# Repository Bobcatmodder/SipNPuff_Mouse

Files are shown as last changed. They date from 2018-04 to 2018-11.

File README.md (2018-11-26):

# The 'Sup - a Mouse for Quadriplegics (SipNPuff_Mouse)

This is a mouse for Quadriplegics and other mobility impaired people, intended to be used with one's mouth. 
This is the repository for code, STL files, and any guides for the mouse, which I show how to build at https://www.instructables.com/id/The-Sup-a-Mouse-for-Quadriplegics-Low-Cost-and-Ope/.

This is a mouse input device intended to be used by Quadriplegics and other mobility impaired people. 
It's a combination of a joystick and a sip-n-puff controller, and is controller by one's mouth. 

Hardware:
Arduino Pro Micro, normal joystick module, and an MPXV7002DP (-0.3 to 0.3 PSI) pressure sensor, enclosed in a 3D printed case.

Software:
A single sketch running on the Arduino, samples values from the joystick and pressure sensor and inputs mouse commands based off that.

If you happen to be wanting one of these but do not wish to build it yourself, please contact me through Instructables. I will be more than happy to make you one at a reasonable price.

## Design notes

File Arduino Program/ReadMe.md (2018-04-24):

The arduino program.

Requires no special libraries or boards, should just be plug and play.

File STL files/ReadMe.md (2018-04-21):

All the STL files.

Mouthpiece03 should be scaled to 1.03 size on the X and Y axis, and left as is for Z (This is to account for shrinkage while annealing). Also print at 100% infill (To keep water from seeping in when it's being washed).

AdapterII is to be printed in a flexible filament.

Lid will print best with supports set to "everywhere", but it may print fine without depending on your printer.

Everything else is fine, just make sure the orientation is OK. If the part shows up too small, simply scale it to 10x size. (They show up too small in Cura)

Other print settings: Speed is default, infill is 45, layer height is best at 0.1MM, but for the frame, lid, and GoProMount files it can be 0.2MM.

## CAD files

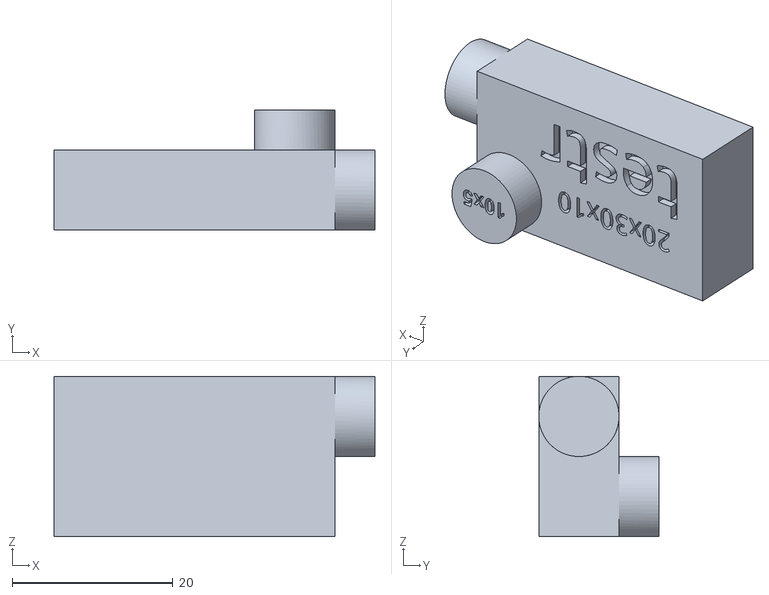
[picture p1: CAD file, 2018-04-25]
STL files/AnnealingTester.stl
40.0 x 15.0 x 20.0

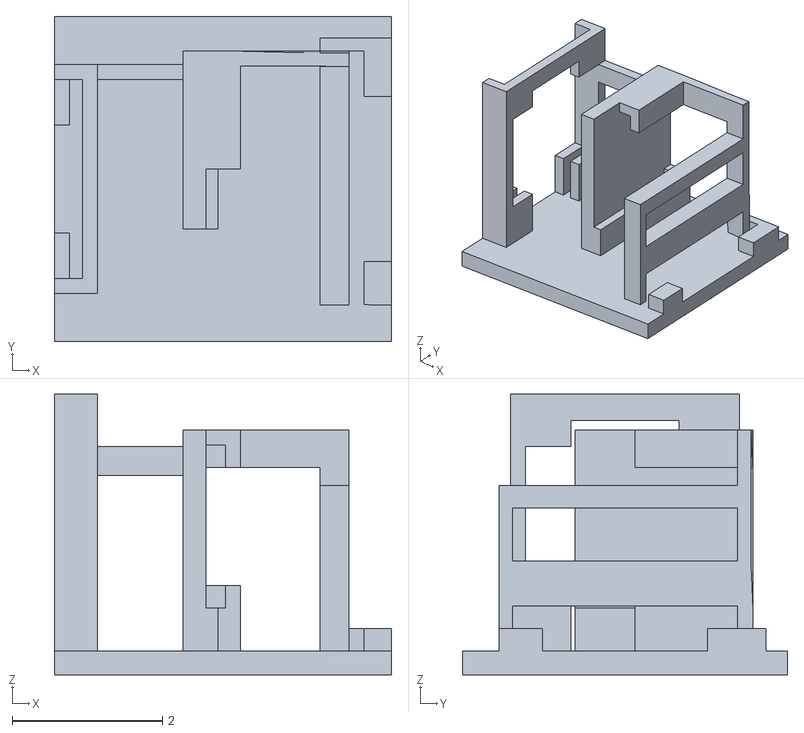
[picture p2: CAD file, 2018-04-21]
STL files/Frame.stl
4.49 x 4.33 x 3.74

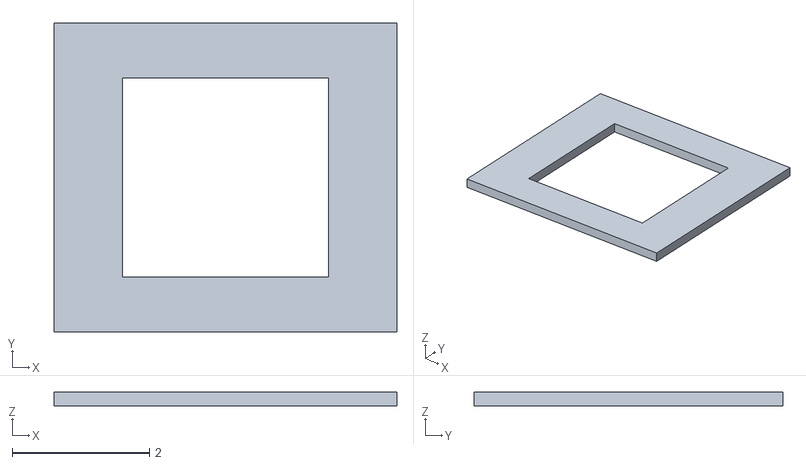
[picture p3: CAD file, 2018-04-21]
STL files/FacePlate.stl
5.00 x 4.50 x 0.2

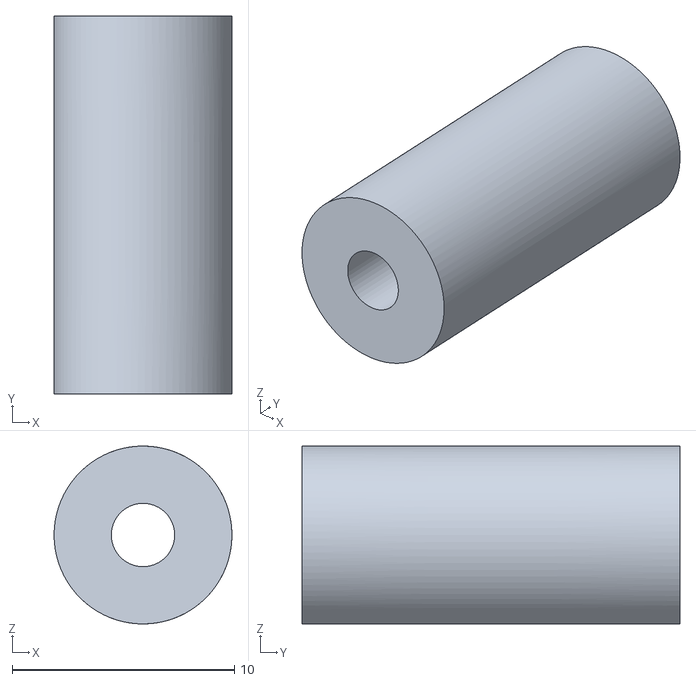
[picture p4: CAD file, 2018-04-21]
STL files/TubingAdapter.stl
8.00 x 17.0 x 8.00

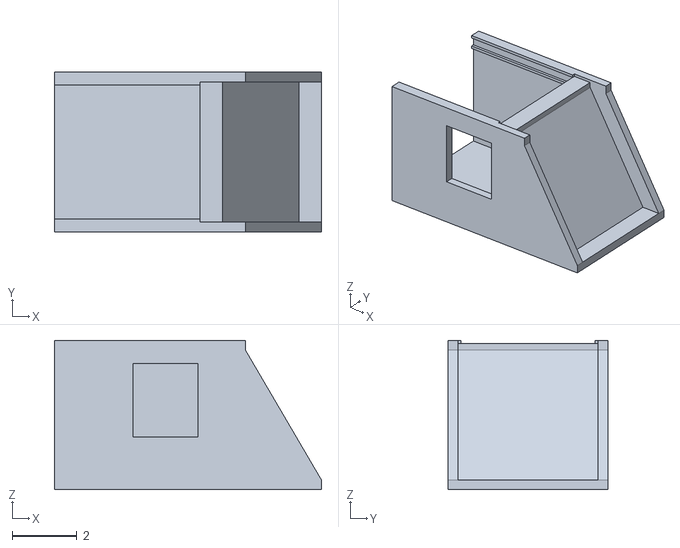
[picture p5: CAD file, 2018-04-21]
STL files/Case.stl
8.23 x 4.93 x 4.61

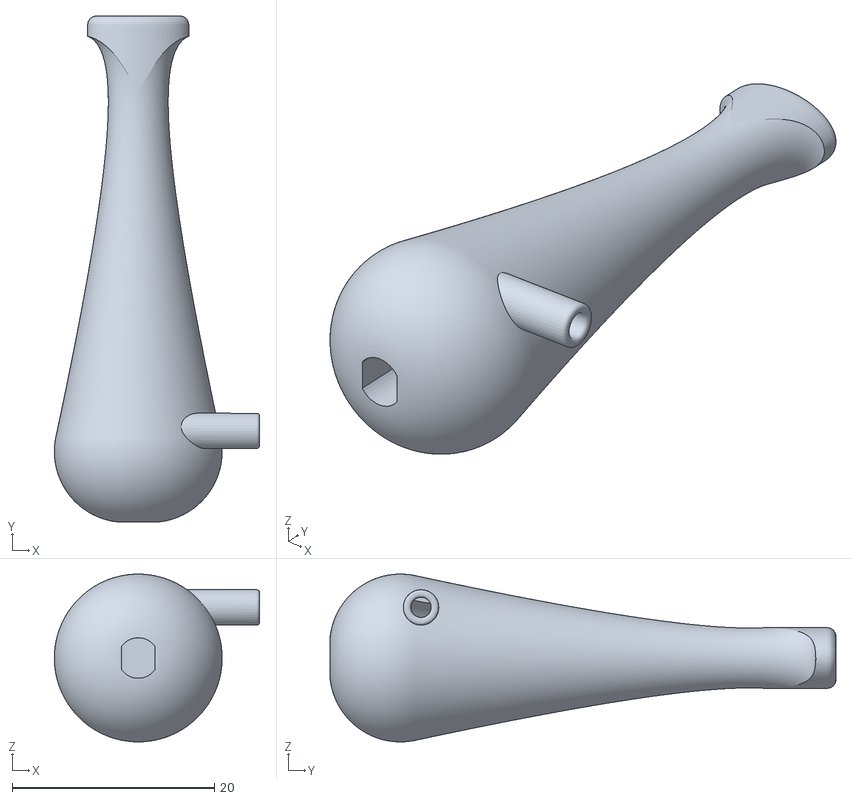
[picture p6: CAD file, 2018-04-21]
STL files/MouthPiece.stl
20.3 x 50.0 x 16.6

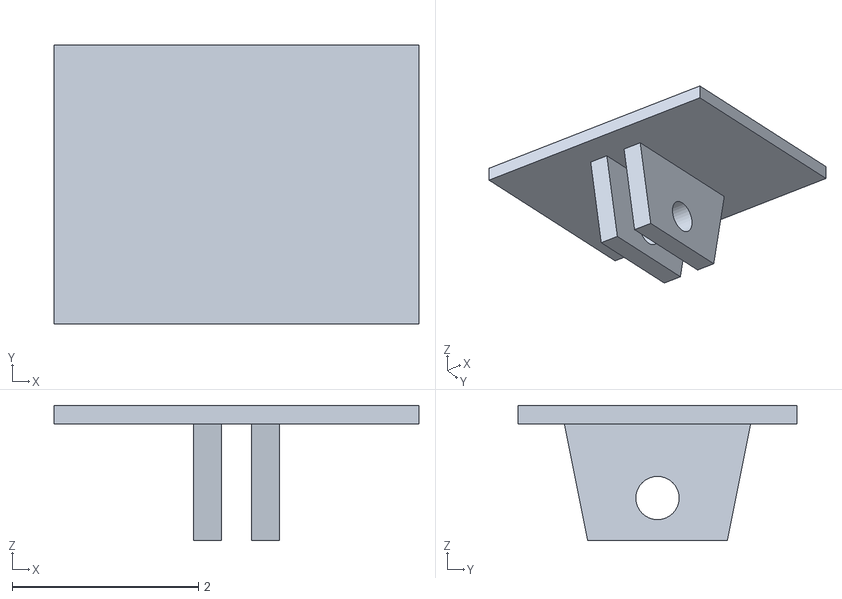
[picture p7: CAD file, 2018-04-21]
STL files/GoProClip.stl
3.92 x 3.00 x 1.45

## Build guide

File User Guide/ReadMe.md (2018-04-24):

User guide here: Currently it's pretty simplistic, for more info check out the Instructable.

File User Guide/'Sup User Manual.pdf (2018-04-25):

## ‘Sup Sip-n-Puff user manual

Mouse actions:
Action: | Input: | Uses:
Hard sip | Right click | Options for folders, files or web links
Soft sip | Scroll down | To move a webpage down
Soft puff | Scroll up | To move a webpage up
Hard puff | Left click | Open programs, files, links, or items.
2 short hard puffs | Double click | To open programs, files or folders
Holding a hard puff | Clicking & dragging | To move items, files, folders, or programs

Copyright © 2018, Jacob Field. This work is licensed under a Creative Commons Attribution 4.0 International License. (http://creativecommons.org/licenses/by/4.0/)

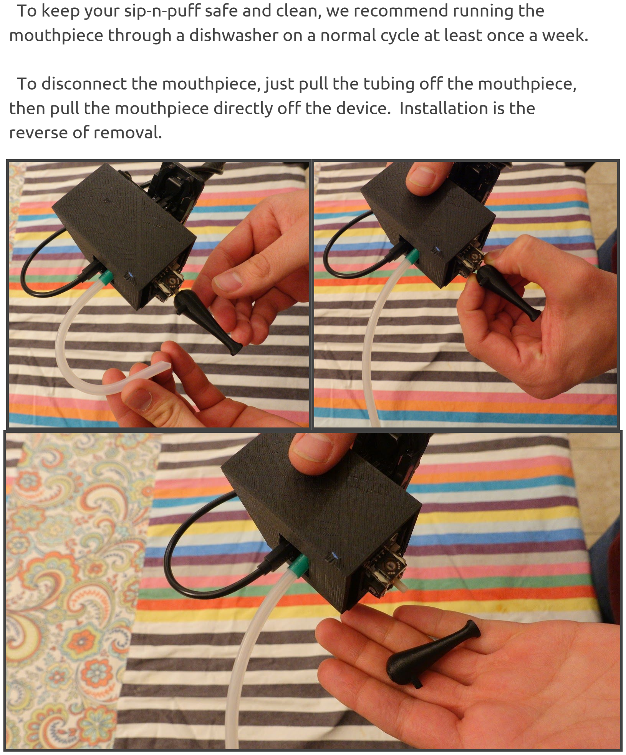
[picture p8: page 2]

To keep your sip-n-puff safe and clean, we recommend running the mouthpiece through a dishwasher on a normal cycle at least once a week.

To disconnect the mouthpiece, just pull the tubing off the mouthpiece, then pull the mouthpiece directly off the device. Installation is the reverse of removal.

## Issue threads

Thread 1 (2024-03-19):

Providing STEP files for SipNPuff

JsonX1ng, 2024-03-19:
Hello!
I'm a student from Simon Fraser University and we're making a SipNPuff fishing rod. I'm interested in integrating your module into our design. Since our team is using an Arduino UNO + prototyping shield instead of the pro micro in your design, we are planning to modify the case, frame and mouthpiece. Would it be possible for you to provide the STEP/F3z/SLDPRT files for the design?

Thanks!
-Jason

Bobcatmodder, 2024-03-20:
Hi Jason!

I might still have the files, but - if your team has any 3D modeling
design, I'm pretty sure you'll be able to make a much better design - I
made these with a friend back in 2017 when we didn't have any experience.
Let me know if you still want the files though!

Jacob

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

Closed 2024-03-27.

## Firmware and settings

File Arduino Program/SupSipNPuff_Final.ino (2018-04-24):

/*
MIT License

Copyright (c) 2018 Jacob Field

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
--The source code, design files, and links to documentation for this project can
--be found at https://github.com/Bobcatmodder/SipNPuff_Mouse/.
*/

#include <Mouse.h>

//Pressure sensor sampling values
volatile byte sampleCounter = 0;
byte sampleLength = 12; //desired sample number minus one because computers are zero indexed
volatile int samples[13];
unsigned long sampleRoutineTimer = 0;
byte samplePeriod = 8;

//Mouse button state trackers
bool isLeftPressed = false;
bool isRightPressed = false;

//Cursor velocity variables (to do with precision and speed)
int wavelength = 15; // Distance/Period (Speed of cursor in pixels/iteration)
int period = 35; // Time/period (MS per iteration)
unsigned long cursorFrequencyTimer = 0; // Variable to time when to update the mouse

//Joystick threshold and analog value storing arrays
int joyThresh[] = {5, 5}; //Deadzone threshholds for X and Y axis of joystick
int reading[] = {0, 0}; //Array for storing the values of the readings from the joystick axis


void setup() { //Setup code, runs once at startup

  Mouse.begin(); //Take control of the mouse

  //Initialize the timers (these are used so we don't have to use a delay() function inside the loop)
  sampleRoutineTimer = millis() + samplePeriod;
  cursorFrequencyTimer = millis() + period;

}



void loop() { //Main loop, runs over and over as fast as possible

  //Code to run the sampling routine roughly every samplePeriod MS
  if (millis() >= sampleRoutineTimer) { //Otherwise if it's equal or less
    samplePressure();//Go run the function to sample the analog value from the pressure sensor
    sampleRoutineTimer = millis() + samplePeriod;//Reset the timer to 25 MS ahead of current millis() value
  }

  //If the sample buffer length has reached the desired number of samples, then X
  if (sampleCounter >= sampleLength + 1) {
    inputMouse(averagePressureValue());
    sampleCounter = 0; // Reset the sample buffer counter to zero
  }

  //Code to run the joystick analog value reading/conversion and mouse updating code every period MS
  if (millis() >= cursorFrequencyTimer) { //Otherwise if it's equal or less
    readAxis(1, 2);
    Mouse.move(reading[0], -reading[1], 0);
    cursorFrequencyTimer = millis() + period;//Reset the timer to 25 MS ahead of current millis() value
  }

}



//----------------Custom Functions----------------

//Sampling function to run every time the timer calls it
void samplePressure() {
  samples[sampleCounter] = analogRead(A0);
  sampleCounter += 1;
}


//Function to return the average value of the sample array
int averagePressureValue(){
  unsigned int averageReading = 0;
    for (byte x = 0; x <= sampleLength; x++) {
      averageReading += samples[x];
    }
    averageReading = averageReading / sampleLength + 1;
    return averageReading;
}


//Function that takes the average sample array pressure value, then sends a mouse command based off that pressure value
void inputMouse(int pressValue){
    if (pressValue < 400) { //Hard sip
      if (!isRightPressed) {
        Mouse.press(MOUSE_RIGHT);
        isRightPressed = true;
      }
    } else if (pressValue > 415 && pressValue < 535) { //Soft sip
      Mouse.move(0, 0, -1);
    } else if (pressValue > 550 && pressValue < 600) {
      if (isLeftPressed) {
        Mouse.release(MOUSE_LEFT);
        isLeftPressed = false;
      }
      if (isRightPressed) {
        Mouse.release(MOUSE_RIGHT);
        isRightPressed = false;
      }
    } else if (pressValue > 615 && pressValue < 675) { //Soft puff
      Mouse.move(0, 0, 1);
    } else if (pressValue > 690) { //Hard puff
      if (!isLeftPressed) {
        Mouse.press(MOUSE_LEFT);
        isLeftPressed = true;
      }
    }
}


//Function to read the analog values from the joystick, remove noise in the deadzone, then convert them to useable +/- values
void readAxis(int pinOne, int pinTwo){
  //Read initial values
  reading[0] = analogRead(pinOne) - 22;
  reading[1] = analogRead(pinTwo);
  //Subtract 511 to get a -511 to 511 value from the 0-1023 value
  for(byte x = 0; x <= 1; x++){
    reading[x] -= 511;
  }
  //Check to see if the values are below the threshold, if so, erase them.
  for(byte x = 0; x <= 1; x++){
    if(abs(reading[x]) < joyThresh[x]){
      reading[x] = 0;
    } else {
      if(reading[x] < 0){
        reading[x] += joyThresh[x];
      } else {
        reading[x] -= joyThresh[x];  
      }
    }
  }
  //Map values to lower numbers, and negative/positive values
  for(byte x = 0; x <= 1; x++){
    reading[x] = reading[x] / (1023 / (wavelength *2)); //map(reading[x], 0, 1023, -cursorSpeed, cursorSpeed); <- This was the old one, I didn't want to rely on that though
  }
}
